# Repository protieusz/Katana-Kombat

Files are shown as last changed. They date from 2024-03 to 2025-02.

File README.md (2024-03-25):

# Katana-Kombat
Katana Kombat: A 39 keys keyboard with Katana layout and a trackball in the center with RGBs. This design will be close source. It will be on sale soon!

Briefly mentioned in https://kbd.news/Behind-the-scenes-159-2330.html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

Thank you, PCBWay for sponsoring my Katana Kombat.  PCBWay is your one stop PCB prototyping shopping services.

Case is a bit too height. Will adjust the case height in the future. ~~Files will be made public shortly.~~ Trackball 3D module component part, you will need to buy it from this designer since he is selling it https://ma-po.booth.pm/items/5258743 and create your own or use my custom created one that is not as fancy or has a clip to prevent the ball from falling out if you turn your keeb upside down.

QMK source code will be uploaded later and also uses template code from Bally and modify according to Katana Kombat matrix.

This design will be close source and will be on sale on a website in the future.

Final Production Pictures:


























Fusion360 Renders:

700A7096-73B3-412D-8E7D-E530743F0638
Screenshot 2024-01-13 at 7 33 31 PM
Screenshot 2024-01-13 at 7 33 00 PM
Screenshot 2024-01-13 at 7 32 37 PM
Screenshot 2024-01-13 at 7 32 02 PM
Screenshot_2024-01-13_at_2 43 45_PM
Screenshot_2024-01-13_at_2 38 57_PM

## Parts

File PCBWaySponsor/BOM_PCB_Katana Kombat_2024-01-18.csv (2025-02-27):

ID | Name | Designator | Footprint | Quantity | Manufacturer Part | Manufacturer | Supplier | Supplier Part | Price | link
1 | NO | +5V1,+3V3,+5V,GND | PIN 1-PIN | 4
2 | SM4007PL | D305,D100,D101,D102,D103,D104,D106,D107,D108,D109,D110,D200,D201,D202,D203,D204,D206,D207,D208,D209,D210,D302,D303,D304,D306,D307,D308,D301,D000,D001,D002,D003,D004,D006,D007,D008,D009,D010,D309 | SOD-123F_L2.8-W1.8-LS3.7-RD | 39 | SM4007PL | MDD | LCSC | C64898 | 0.007 | https://item.szlcsc.com/60254.html
3 | XC6206P332MR | U5-LDO | SOT-23-3_L2.9-W1.6-P1.90-LS2.8-BR | 1 | XC6206P332MR | TOREX(特瑞仕) | LCSC | C5446 | 0.111 | https://item.szlcsc.com/14454.html
4 | 1uF | C1-1UF,C2-1UF,C5-1UF,C6-1UF,C9-1UF | C0805 | 5 | CC0805KKX5R8BB105 | YAGEO(国巨) | LCSC | C408908 | 0.011 | https://item.szlcsc.com/373011.html
5 | 22pF | C3-22PF,C4-22PF | C0805 | 2 | CL21C220JBANNNC | SAMSUNG(三星) | LCSC | C1804 | 0.013 | https://item.szlcsc.com/373011.html
6 | 100nF | C7-100NF,C10-100NF,C11-100NF,C12-100NF,C13-100NF,C14-100NF,C15-100NF,C16-100NF | C0805 | 8 | CC0805KRX7R7BB104 | YAGEO(国巨) | LCSC | C519980 | 0.008 | https://item.szlcsc.com/373011.html
7 | 10uF | C8-10UF | C1206 | 1 | CL31A106MQHNNNE | SAMSUNG(三星) | LCSC | C723915 | 0.043 | https://item.szlcsc.com/89171.html
8 | 4.7uF | C17,C19,C20 | C0402 | 3 | CL05A475MP5NRNC | SAMSUNG(三星) | LCSC | C23733 | 0.006 | https://lcsc.com/eda_search?q=C23733&%26type=1&ref=editor
9 | 100nF | C18 | C0402 | 1 | CL05B104KB54PNC | SAMSUNG(三星) | LCSC | C307331 | 0.006 | https://lcsc.com/eda_search?q=C307331&%26type=1&ref=editor
10 | PRTR5V0U2X,215 | D1-ESD | SOT-143_L2.9-W1.3-P1.92-LS2.3-BR | 1 | PRTR5V0U2X,215 | Nexperia(安世) | LCSC | C12333 | 0.141 | https://item.szlcsc.com/280548.html
11 | BSMD0805-020-15V | F1-FUSE | F0805 | 1 | BSMD0805-020-15V | BHFUSE(佰宏) | LCSC | C883103 | 0.045 | https://item.szlcsc.com/343298.html
12 | 5.1kΩ | R1,R2,R3,R4,R5 | R0805 | 5 | 0805W8F5101T5E | UNI-ROYAL(厚声) | LCSC | C27834 | 0.002 | https://lcsc.com/eda_search?q=C27834&%26type=1&ref=editor
13 | 1kΩ | R6-1K,R7-1K | R0402 | 2 | 0402WGF1001TCE | UNI-ROYAL(厚声) | LCSC | C11702 | 0.001 | https://item.szlcsc.com/323315.html
14 | 27Ω | R8,R9 | R0603 | 2 | 0603WAF270JT5E | UNI-ROYAL(厚声) | LCSC | C25190 | 0.001 | https://www.mouser.in/datasheet/2/447/PYu_RT_1_to_0_01_RoHS_L_11-1669912.pdf
15 | 10kΩ | R10,R12,R13 | R0402 | 3 | 0402WGF1002TCE | UNI-ROYAL(厚声) | LCSC | C25744 | 0.001 | https://lcsc.com/eda_search?q=C25744&%26type=1&ref=editor
16 | 39Ω | R11 | R0402 | 1 | 0402WGJ0390TCE | UNI-ROYAL(厚声) | LCSC | C25164 |  | https://lcsc.com/eda_search?q=C25164&%26type=1&ref=editor
17 | 15kΩ | R14 | R0402 | 1 | 0402WGF1502TCE | UNI-ROYAL(厚声) | LCSC | C25756 | 0.001 | https://lcsc.com/eda_search?q=C25756&%26type=1&ref=editor
18 | RP2040 | U0-RP2040 | LQFN-56_L7.0-W7.0-P0.4-EP | 1 | RP2040 | Raspberry Pi(树莓派) | LCSC | C2040 | 1.076 | https://atta.szlcsc.com/upload/public/pdf/source/20210621/C2040_96F425825606B7957D87DD32E2512CA9.pdf
19 | RESET SWITCH | U1-RESET | RESET SWITCH | 1
20 | BOOT SWITCH | U2-BOOTSEL | RESET SWITCH | 1
21 | PMW3360DM-T2QU | U7 | PMW3360DM-T2QU.PACK | 1 | PMW3360DM-T2QU |  |  |  |  | http://www.pixart.com/upload/PMS0058-PMW3360DM-T2QU-NNDS-R1.30-06042016_20160902201411.pdf
22 | AP2127K-ADJTRG1 | U8 | SOT-23-5_L3.0-W1.7-P0.95-LS2.8-BR | 1 | AP2127K-ADJTRG1 | DIODES(美台) | LCSC | C96343 | 0.059 | https://lcsc.com/eda_search?q=C96343&%26type=1&ref=editor
23 | SK6812MINI-E_C5149201 | U13,U14,U15,U16,U17,U18,U19,U20,U21,U22,U23,U24,U25,U26,U27,U28,U29,U30 | LED-SMD_L3.2-W2.8-TR | 18 | SK6812MINI-E | 欧思科光电 | LCSC | C5149201 | 0.157 | https://lcsc.com/eda_search?q=C5149201&%26type=1&ref=editor
24 | SN74LVC1T45QDCKRQ1 | U35 | SC-70-6_L2.0-W1.3-P0.65-LS2.1-BR | 1 | SN74LVC1T45QDCKRQ1 | TI(德州仪器) | LCSC | C139353 | 0.613 | https://lcsc.com/eda_search?q=C139353&%26type=1&ref=editor
25 | W25Q128JVSIQTR | U40-FLASHCHIP | SOIC-8_L5.3-W5.3-P1.27-LS8.0-BL | 1 | W25Q128JVSIQ | WINBOND(华邦) | LCSC | C97521 | 0.622 | https://item.szlcsc.com/63461.html
26 | TYPE-C-31-M-12 | USBC1 | USB-C_SMD-TYPE-C-31-M-12 | 1 | TYPE-C-31-M-12 | 韩国韩荣 | LCSC | C165948 | 0.161 | https://so.szlcsc.com/global.html?c=&k=C165948
27 | 12MHz | X1-12MHZ | OSC-SMD_4P-L3.2-W2.5-BL | 1 | X322512MSB4SI | YXC(扬兴晶振) | LCSC | C9002 | 0.059 | https://item.szlcsc.com/15866.html
28 | Switch | K100,K101,K102,K103,K104,K106,K107,K108,K109,K110,K200,K201,K202,K203,K204,K206,K207,K208,K209,K210,K302,K303,K304,K306,K307,K308,K301,K305,K000,K001,K002,K003,K004,K006,K007,K008,K009,K010,K309 | CHERRY_MX_100_MILLMAX | 39

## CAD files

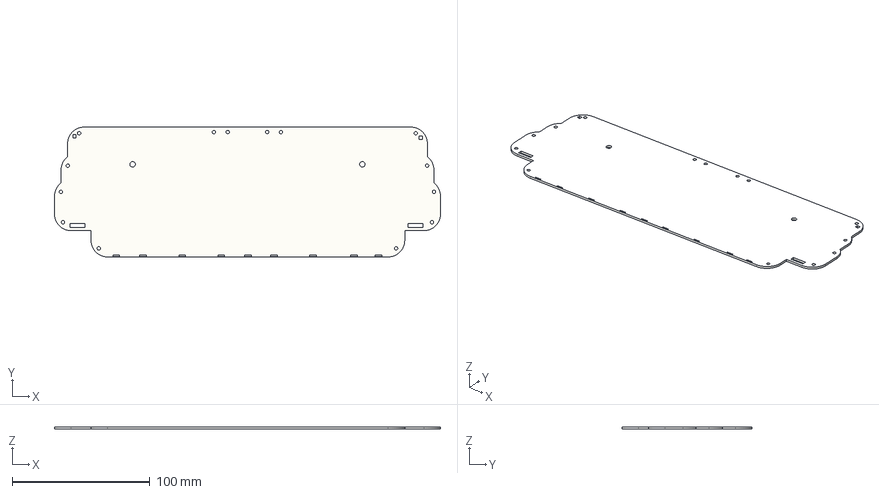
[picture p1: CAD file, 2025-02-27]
Improved Top Case Lower profile/KatanaKombatBottomplate.step
279.9 x 94.2 x 1.60 mm

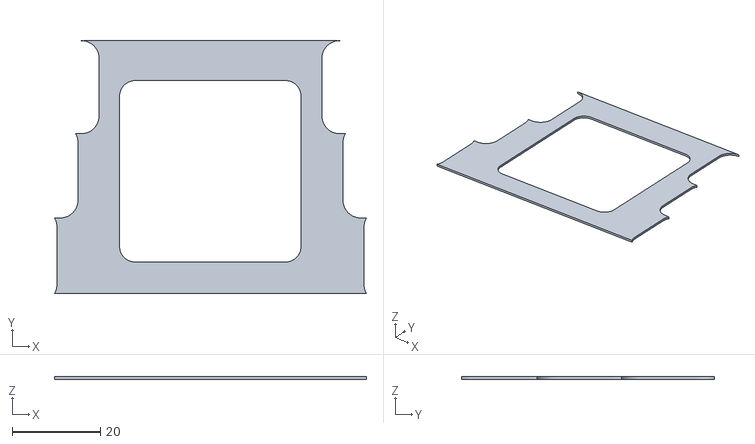
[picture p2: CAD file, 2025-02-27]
STL Final/RGB Diffuser.stl
70.5 x 57.2 x 0.6

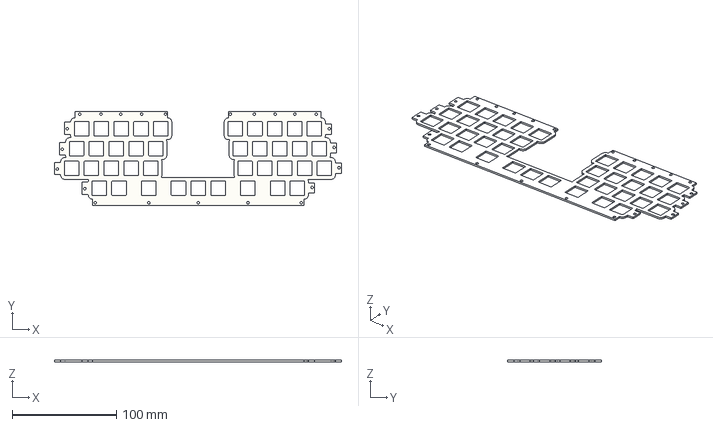
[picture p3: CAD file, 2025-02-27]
Improved Top Case Lower profile/KatanaKombat SwitchPlate.step
275.8 x 90.2 x 1.50 mm

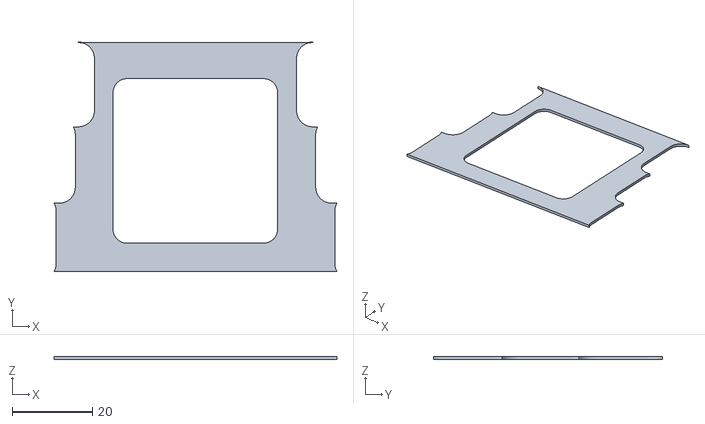
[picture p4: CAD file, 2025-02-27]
STL Final/RGB Diffuser0.8mm.stl
70.5 x 57.2 x 0.8

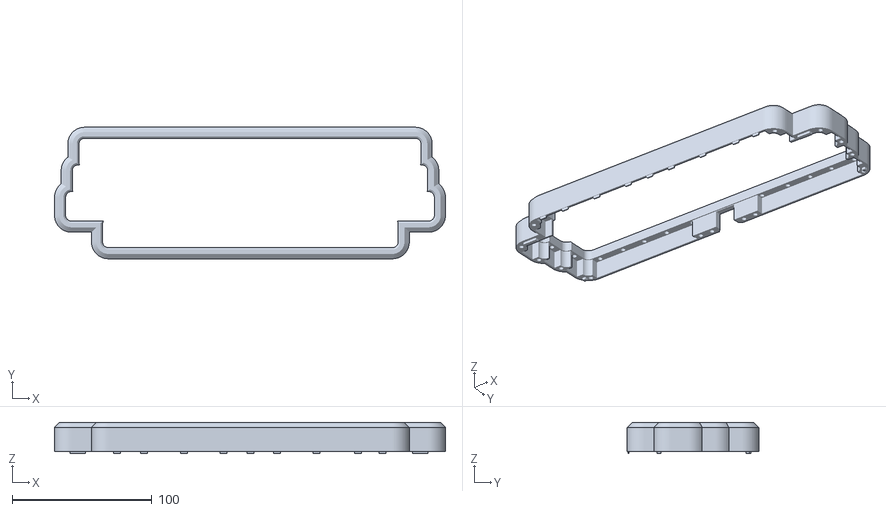
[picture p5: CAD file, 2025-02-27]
STL Final/KKTopCase_lower_height.stl
279.9 x 94.2 x 22.2

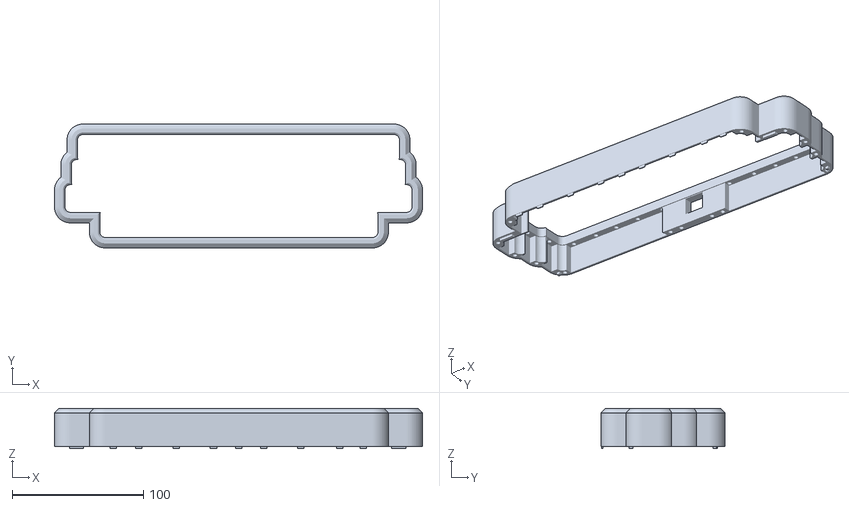
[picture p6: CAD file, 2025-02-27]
STL Final/KKTopCase.stl
279.9 x 94.2 x 30.8

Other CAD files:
Improved Top Case Lower profile/KatanaKombat RGB Diffuser.step
Improved Top Case Lower profile/KatanaKombat Top.step
STL Final/KKSwitchPlate.stl
STL Final/KKBottomPlate.stl

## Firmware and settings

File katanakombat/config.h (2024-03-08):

// Copyright 2023 aki27 (@aki27kbd)
// SPDX-License-Identifier: GPL-2.0-or-later

#pragma once

//#define VIAL_KEYBOARD_UID {0xC4, 0x18, 0xCC, 0x6D, 0x1C, 0x16, 0x5B, 0x8D}
//#define VIAL_UNLOCK_COMBO_ROWS {0, 0}
//#define VIAL_UNLOCK_COMBO_COLS {1, 11}

/* VIA */
//#define DYNAMIC_KEYMAP_LAYER_COUNT 8


/* key matrix size */
//#define MATRIX_COLS 13
//#define MATRIX_ROWS 4


/* tapping term */
// #define TAPPING_FORCE_HOLD
//#define TAPPING_TERM 200
// #define IGNORE_MOD_TAP_INTERRUPT

#define RP2040_BOOTLOADER_DOUBLE_TAP_RESET // Activates the double-tap behavior
#define RP2040_BOOTLOADER_DOUBLE_TAP_RESET_TIMEOUT 200U // Timeout window in ms in which the double tap can occur.

#ifdef COMBO_ENABLE
#    define COMBO_COUNT 6
#    define COMBO_TERM 200
#endif

/* Encoder */
//#define ENCODERS_PAD_A { GP11 }
//#define ENCODERS_PAD_B { GP12 }
//#define ENCODER_RESOLUTION 4

/* Matrix*/
//#define MATRIX_COL_PINS { GP25, GP24, GP23, GP22, GP21, GP26, GP27, GP20, GP19, GP18, GP17, GP16, GP13 }
//#define MATRIX_ROW_PINS { GP28, GP10, GP14, GP15 }

/* COL2ROW, ROW2COL */
//#define DIODE_DIRECTION COL2ROW


/* Set 0 if debouncing isn't needed */
//#define DEBOUNCE 5


/* Mechanical locking support. Use KC_LCAP, KC_LNUM or KC_LSCR instead in keymap (Very Important for Scroll Lock!!!) */
#undef LOCKING_SUPPORT_ENABLE
/* Locking resynchronize hack */
#undef LOCKING_RESYNC_ENABLE


/* RGB LED */
//#define WS2812_PIO_USE_PIO1
#define WS2812_DI_PIN GP29

#ifdef RGBLIGHT_ENABLE
    #define RGBLED_NUM 18
    #define RGBLIGHT_LIMIT_VAL 80
    #define RGBLIGHT_HUE_STEP 10
    #define RGBLIGHT_SAT_STEP 17
    #define RGBLIGHT_VAL_STEP 17

    // #define RGBLIGHT_ANIMATIONS
    #define RGBLIGHT_EFFECT_BREATHING
    #define RGBLIGHT_EFFECT_RAINBOW_MOOD
    #define RGBLIGHT_EFFECT_RAINBOW_SWIRL
    #define RGBLIGHT_EFFECT_SNAKE
    #define RGBLIGHT_EFFECT_KNIGHT
    #define RGBLIGHT_EFFECT_CHRISTMAS
    #define RGBLIGHT_EFFECT_STATIC_GRADIENT
    #define RGBLIGHT_EFFECT_TWINKLE
    #define RGBLIGHT_EFFECT_ALTERNATING
#endif


/* Trackball */

#ifdef POINTING_DEVICE_ENABLE

//#    undef RP_SPI_USE_SPI0
//#    define RP_SPI_USE_SPI0 TRUE
//#    undef RP_SPI_USE_SPI1
//#    define RP_SPI_USE_SPI1 FALSE
#    define SPI_DRIVER SPID0

//#    define SPI_SCK_PIN GP22 //6
//#    define SPI_MISO_PIN GP24 //4
//#    define SPI_MOSI_PIN GP23 //7
#    define SPI_SCK_PIN GP18
#    define SPI_MISO_PIN GP16
#    define SPI_MOSI_PIN GP19

#endif


#ifndef PMW33XX_CS_PIN
#    define PMW33XX_CS_PIN GP17
#endif
#define POINTING_DEVICE_INVERT_X
#define POINTING_DEVICE_INVERT_Y
//#define ROTATIONAL_TRANSFORM_ANGLE 90
#define POINTING_DEVICE_ROTATION_180

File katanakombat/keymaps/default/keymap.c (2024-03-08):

/*
Copyright 2022 aki27

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
You should have received a copy of the GNU General Public License
along with this program.  If not, see <http://www.gnu.org/licenses/>.
*/

#include QMK_KEYBOARD_H

enum combo_events {
  COMBO_DEL,
  COMBO_ESC,
  //COMBO_RCLICK,
  COMBO_LENGTH
};
uint16_t COMBO_LEN = COMBO_LENGTH;

const uint16_t PROGMEM combo_del[] = {KC_Y, KC_H, COMBO_END};
const uint16_t PROGMEM combo_esc[] = {KC_T, KC_G, COMBO_END};
//const uint16_t PROGMEM combo_rclick[] = {KC_MS_BTN1, SCRL_MO, COMBO_END};

combo_t key_combos[] = {
  [COMBO_DEL] = COMBO(combo_del, KC_DEL),
  [COMBO_ESC] = COMBO(combo_esc, KC_ESC),
  //[COMBO_RCLICK] = COMBO(combo_rclick, KC_MS_BTN2),
};

layer_state_t layer_state_set_user(layer_state_t state) {
    return update_tri_layer_state(state, 1, 2, 3);
} 

enum layer_names {
  _BASE,
  _FN1,
  _FN2,
  _FN3
};

const uint16_t PROGMEM keymaps[][MATRIX_ROWS][MATRIX_COLS] = {
    
    [_BASE] = LAYOUT(
        KC_Q,         KC_W, KC_E,    KC_R,    KC_T,                                           KC_Y,          KC_U,          KC_I,     KC_O,   KC_P,
        KC_A,         KC_S, KC_D,    KC_F,    KC_G,                                           KC_H,          KC_J,          KC_K,     KC_L,   KC_SCLN,
        LSFT_T(KC_Z), KC_X, KC_C,    KC_V,    KC_B,                                           KC_N,          KC_M,          KC_COMMA, KC_DOT, RSFT_T(KC_SLSH),
                            KC_LGUI, KC_LCTL, LT(1,KC_BSPC), KC_MS_BTN2, KC_MS_BTN1, SCRL_MO, LT(2,KC_SPC),  (KC_ENT),     KC_LALT
    ),
    [_FN1] = LAYOUT(
        KC_1,    KC_2,    KC_3,    KC_4,    KC_5,                                    KC_6,     KC_7,    KC_8,    KC_9,    KC_0,
        KC_TAB,  _______, _______, _______, _______,                                 KC_MINS,  KC_EQL,  KC_LBRC, KC_RBRC, KC_QUOT,
        _______, _______, KC_MUTE, KC_VOLD, KC_VOLU,                                 KC_TILD,  KC_GRV,  _______, _______, KC_BSLS,
                          _______, _______, _______,     _______, _______, _______,  _______,  _______, _______
    ),
    [_FN2] = LAYOUT(
        KC_EXLM, KC_AT,   KC_HASH, KC_DLR,  KC_PERC,                                KC_CIRC, KC_AMPR, KC_ASTR, KC_LPRN, KC_RPRN,
        RGB_VAI,  RGB_SAI,    RGB_HUI,    RGB_SPI,   RGB_MOD,                       RGB_TOG,  _______,  _______,   _______, _______,
        RGB_VAD,  RGB_SAD,    RGB_HUD,    RGB_SPD,   RGB_RMOD,                      _______,  _______, _______, _______, _______,
                          _______, _______, _______,     _______, _______, _______, _______,  _______, _______
    ),
    [_FN3] = LAYOUT(
        _______, KC_UP, _______, _______, _______,                                    KC_F1,   KC_F2,   KC_F3,   KC_F4,   KC_PSCR,
        KC_LEFT, KC_DOWN, KC_RIGHT, _______, _______,                                 KC_F5,   KC_F6,   KC_F7,   KC_F8,   KC_F9,
        _______, _______, ROT_L15, ROT_R15, CPI_SW,                                   KC_F10,  KC_F11,  KC_F12,  _______, _______,
                          _______, _______, _______,     _______, _______, _______,   _______, _______, _______
    )
};

//bool encoder_update_user(uint8_t index, bool clockwise) {
    //if (index == 0) {
        //if (clockwise) {
            //tap_code(KC_VOLD);
            //tap_code(KC_MS_WH_UP);
        //} else {
            //tap_code(KC_VOLU);
            //tap_code(KC_MS_WH_DOWN);
        //}
    //}
    //return true;
//}

//#if defined(ENCODER_MAP_ENABLE)
//const uint16_t PROGMEM encoder_map[][NUM_ENCODERS][2] = {
    //[0] =  { ENCODER_CCW_CW(KC_MS_WH_UP, KC_MS_WH_DOWN)  },
    //[1] =  { ENCODER_CCW_CW(KC_MS_WH_LEFT, KC_MS_WH_RIGHT)  },
    //[2] =  { ENCODER_CCW_CW(KC_PGUP, KC_PGDN)  },
    //[3] =  { ENCODER_CCW_CW(KC_VOLD, KC_VOLU)  } 
    //[4] =  { ENCODER_CCW_CW(XXXXXXX, XXXXXXX) }
//};
//#endif

//keyevent_t encoder1_ccw = {
    //.key = (keypos_t){.row = 3, .col = 0},
    //.pressed = false
//};

//keyevent_t encoder1_cw = {
    //.key = (keypos_t){.row = 3, .col = 9},
    //.pressed = false
//};

//bool encoder_update_user(uint8_t index, bool clockwise) {
    //if (index == 0) { /* First encoder */
        //if (clockwise) {
            //encoder1_cw.pressed = true;
            //encoder1_cw.time = (timer_read() | 1);
            //action_exec(encoder1_cw);
        //} else {
            //encoder1_ccw.pressed = true;
            //encoder1_ccw.time = (timer_read() | 1);
            //action_exec(encoder1_ccw);
        //}
    //}

    //return true;
//}

//void matrix_scan_user(void) {

    //if (IS_PRESSED(encoder1_ccw)) {
        //encoder1_ccw.pressed = false;
        //encoder1_ccw.time = (timer_read() | 1);
        //action_exec(encoder1_ccw);
    //}

    //if (IS_PRESSED(encoder1_cw)) {
        //encoder1_cw.pressed = false;
        //encoder1_cw.time = (timer_read() | 1);
        //action_exec(encoder1_cw);
    //}

//}

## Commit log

2025-02-27 Gerbers, BOM, components placement
    [BOM_PCB_Katana Kombat_2024-01-18.csv, PickAndPlace_PCB_Katana Kombat_2024-01-18.csv]
2025-02-27 Stl case files
    [KKBottomPlate.stl, KKSwitchPlate.stl, KKTopCase.stl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]
2025-02-27 Case STEP files
    [KatanaKombat RGB Diffuser.step, KatanaKombat SwitchPlate.step, KatanaKombat Top.step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]

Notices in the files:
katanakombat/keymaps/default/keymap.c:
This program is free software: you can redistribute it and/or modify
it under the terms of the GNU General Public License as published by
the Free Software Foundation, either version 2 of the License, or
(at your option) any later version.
